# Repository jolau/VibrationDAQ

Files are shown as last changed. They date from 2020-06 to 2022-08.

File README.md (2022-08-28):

# VibrationDAQ
Data Acquisition (DAQ) of the [Analog Devices ADcmXL3021](https://www.analog.com/en/products/adcmxl3021.html#product-overview) vibration sensor. The VibrationDAQ was developed as part of an internship at [Wingtra](https://wingtra.com/) by [Jonas Lauener](https://www.jolau.ch/).  

**For any technical questions, please open an issue: https://github.com/jolau/VibrationDAQ/issues/new/choose**

Copyright (c) 2020, Jonas Lauener & Wingtra AG\


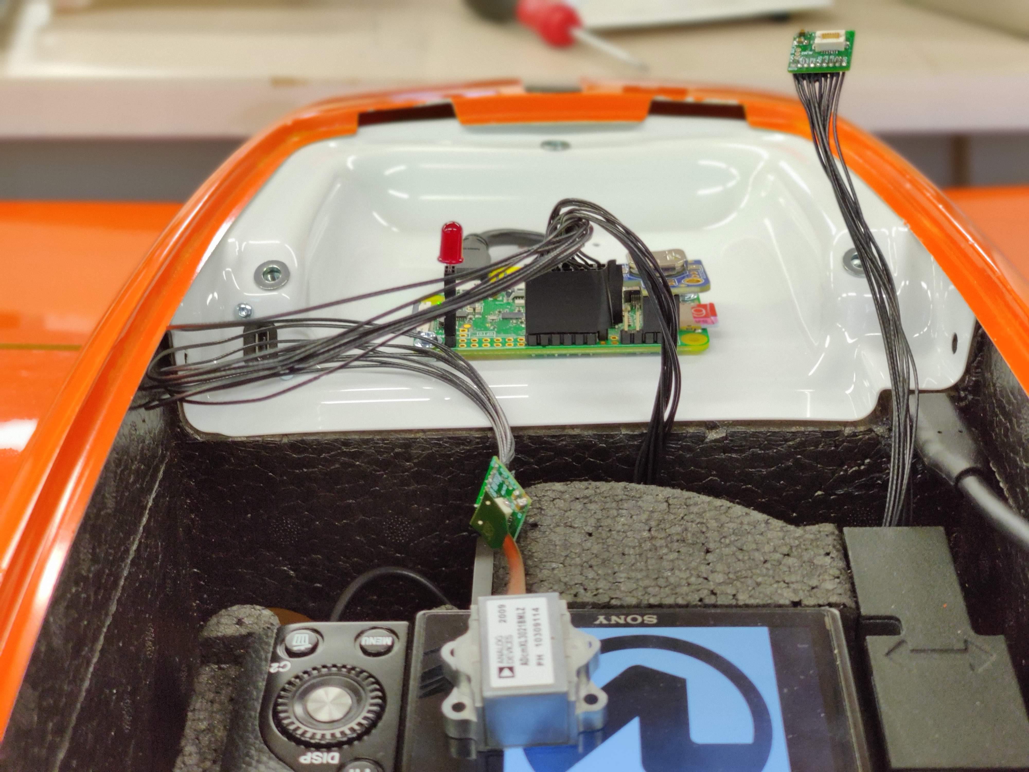
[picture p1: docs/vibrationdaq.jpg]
VibrationDAQ


## Hardware
- Raspberry Pi 
- [Analog Devices ADcmXL3021](https://www.analog.com/en/products/adcmxl3021.html#product-overview) vibration sensor capabilities
    - [Corrected data sheet](docs/ADcmXL3021_corrected.pdf)
    - Sensor orientation:\
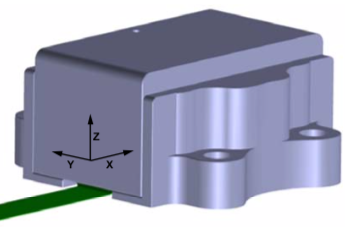
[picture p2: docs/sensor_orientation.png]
Sensor Orientation
    
    - Mass: 13 g
    - Frequencies up to 110 kHz
    - ±50 g measurement range
    - MFFT mode: Spectral analysis through internal FFT\
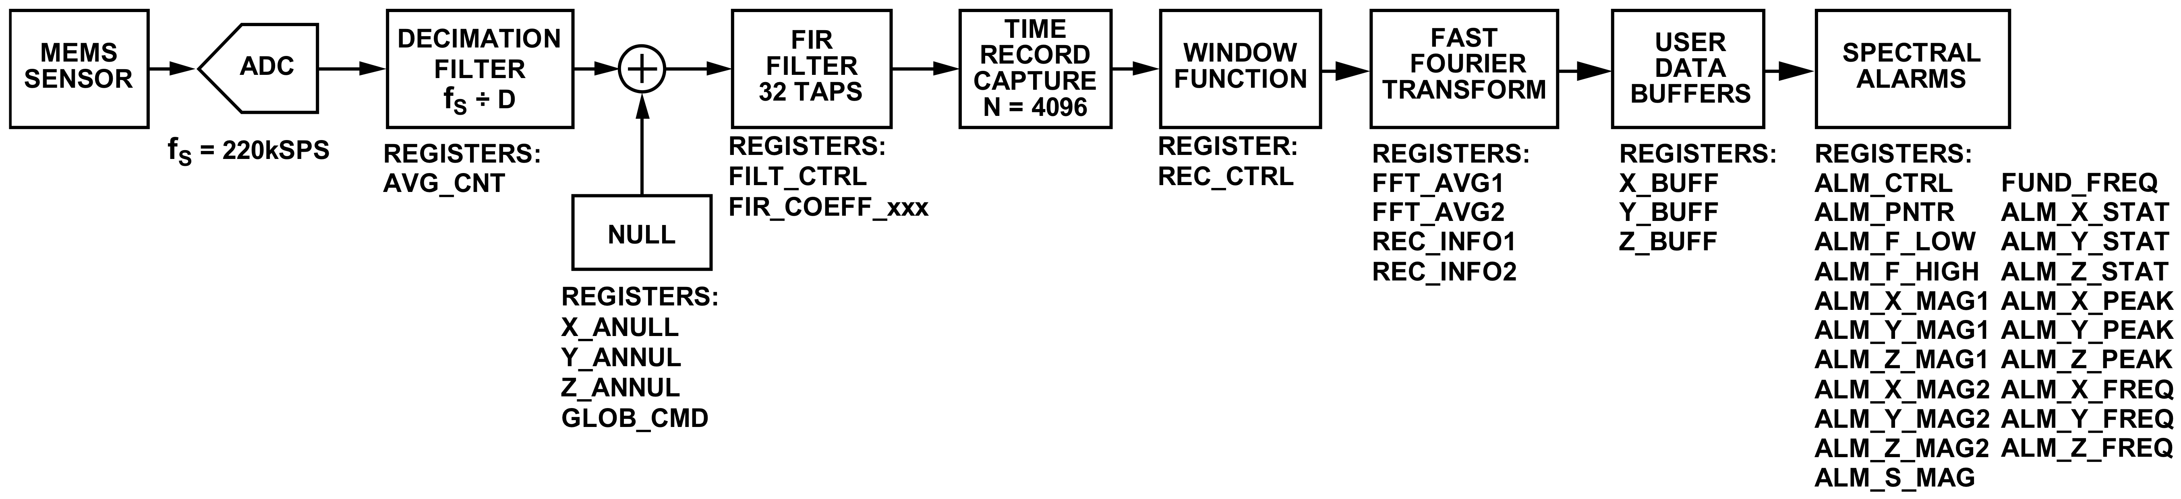
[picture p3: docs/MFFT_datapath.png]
MFFT datapath
    
        - 2048 bins per axis with user configurable bin sizes from 0.42 Hz to 53.7 Hz
        - Windowing options: rectangular, Hanning, flat top
    - MTC mode: Time domain capture\
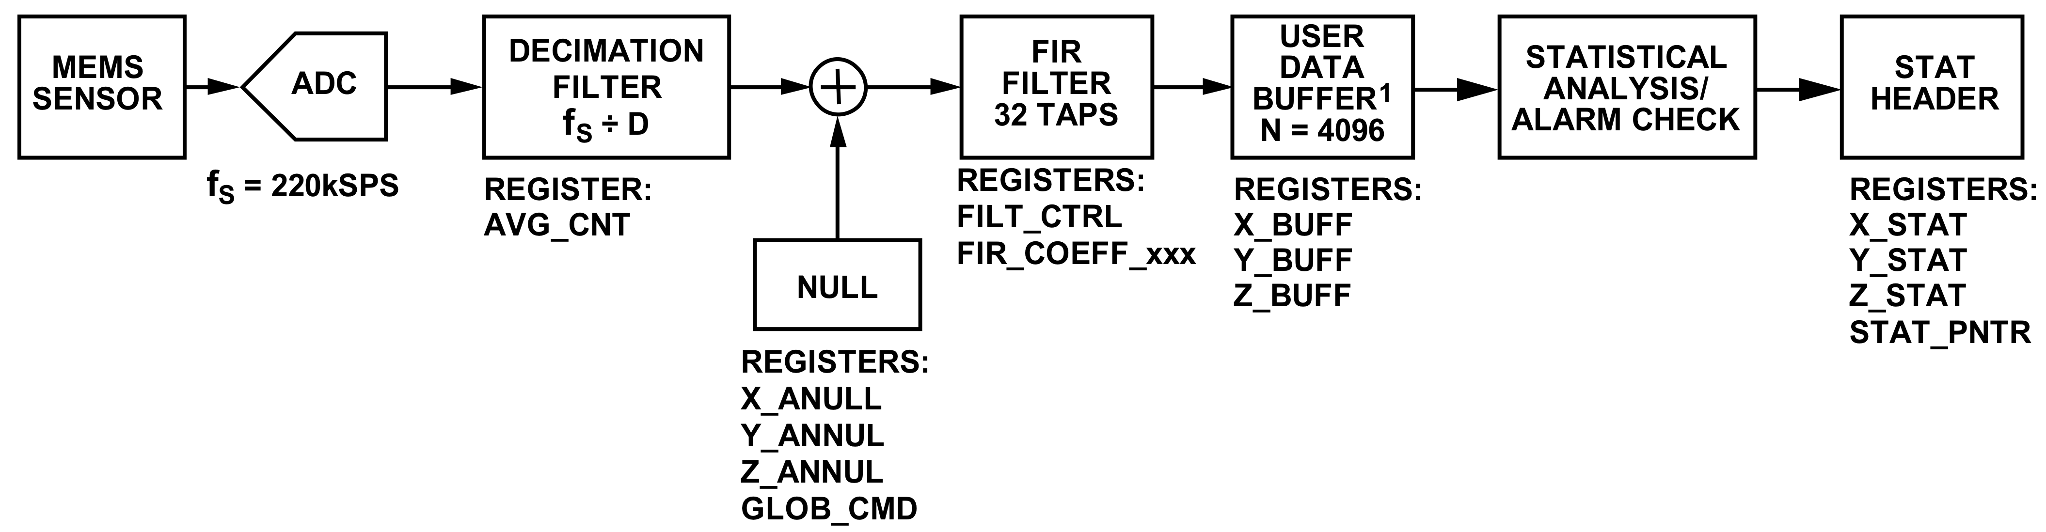
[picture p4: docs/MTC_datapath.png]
MTC datapath
    
        - 4096 samples per axis
- [Features a status LED](#status-led)

### Pinout Raspberry Pi
pinout rpi

| | pin | pin | |
|---|-----|-----|---|
| RST 1 | 13  | | |
| BSY 1 | 15  | 16  | RST 2 |
| 3V3 | 17  | 18  | BSY 2 |
| MOSI  | 19  | 20  | EMPTY |
| MISO  | 21  | 22  | SYNC  |
| SCLK  | 23  | 24  | CE 1  |
| GND | 25  | 26  | CE 2  |

The vibration sensor only works on the main SPI pins (SPI0) of the Raspberry Pi - the other SPI ports don't support SPI mode 3.

### Custom adapter board
The pins of the ADcmXL3021 vibration sensor can be accessed by using a custom adapter board. The PCB was created by using the software KiCad: [KiCad project files](ADcmXL3021_adapter/ADcmXL3021_adapter.pro)\
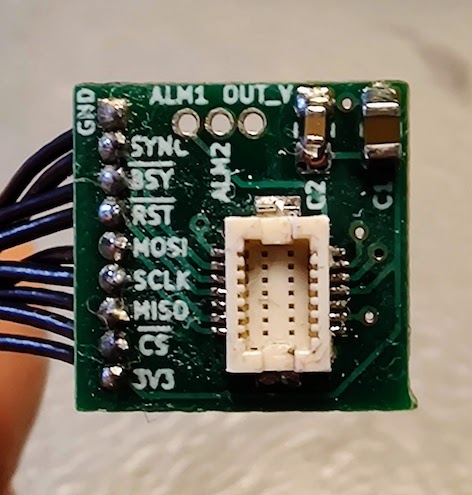
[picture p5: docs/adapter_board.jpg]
adapter board


## Installation
_In case you want to setup your own VibrationDAQ on a Raspberry Pi:_
1. Install yaml-cpp (as described below)
2. Clone this repo.
3. `cd VibrationDAQ`
4. `mkdir build & cd build`
5. `cmake ..`
6. `sudo make install`

Make sure that you have [enabled SPI](https://www.raspberrypi-spy.co.uk/2014/08/enabling-the-spi-interface-on-the-raspberry-pi/).

You can use it now with `vibration_daq_app [full path to config.yaml]`.

#### Installation of yaml-cpp
1. `wget https://github.com/jbeder/yaml-cpp/archive/yaml-cpp-0.6.3.tar.gz`
2. `tar -xvf yaml-cpp-0.6.3.tar.gz`
3. `cd yaml-cpp-yaml-cpp-0.6.3/`
4. `mkdir build`
5. `cd build`
6. `cmake .. -DYAML_BUILD_SHARED_LIBS=ON`
7. `sudo make install`

### Enable/Disable auto-start
1. Edit config.yaml path in vibration_daq.service file to own needs 
2. `sudo systemctl enable [full path to vibration_daq.service file]`    
    This automatically links the service and enables it. Replace `enable` with `disable` to disable service.

## Dependencies
Many thanks to the authors of the following libraries:
- [yaml-cpp](https://github.com/jbeder/yaml-cpp)
- [loguru](https://github.com/emilk/loguru)
- [c-periphery](https://github.com/vsergeev/c-periphery)
- [date](https://github.com/HowardHinnant/date)

## Usage
### Workflow
1. Connect to the Raspberry Pi and adapt the `~/Documents/config.yaml` to your requirements. Make sure that auto-start is enabled. If it's the first time you use it, test it by running it manually: `vibration_daq_app [full path to config.yaml]`
2. Mount the vibration sensor with the double sided tape [3M™ Adhesive Transfer Tape 950](https://www.digikey.ch/product-detail/en/3m-tc/3-4-5-950/3M9743-ND/2649288). This shouldn't distort the vibration too much.
3. Do your measurement.
4. Download the collected data over SFTP. I recommend to also download the used config file.
6. Open a vibration CSV file in Google Sheets. 
    - For FFT measurement: 
        - Hide the first two data points as these have usually very high magnitude and don't give meaningful information
        - Plot the data using a column chart.  

### Status led
If the status led is enabled in config, it will glow when running:
- Constant glow: data acquisition is running normally
- Blink: measurement completed, saving data to a new csv file

## Config file
Short primer on the syntax of yaml: https://learnxinyminutes.com/docs/yaml/

### Decimation Filter
Setting the right `decimation_factor` is crucial for getting meaningful data. Choose it according to the maximum vibration frequency you're expecting.
Of course, the decimation factor also affects the predefined FIR filters i.e. with a FACTOR_64, the LOW_PASS_10kHz is actually a 156 Hz low pass filter.  
 
| **decimation_factor** | **Effective Sample Rate, fS (SPS)** | **Effective FFT Bin Size, f_MIN (Hz)** | **Effective Maximum FFT Frequency, f_MAX (Hz)** |
|---|---|---|---|
| FACTOR_1 | 220000 | 53.71094 | 110000 |
| FACTOR_2 | 110000 | 26.85547 | 55000 |
| FACTOR_4 | 55000 | 13.42773 | 27500 |
| FACTOR_8 | 27500 | 6.713867 | 13750 |
| FACTOR_16 | 13750 | 3.356934 | 6875 |
| FACTOR_32 | 6875 | 1.678467 | 3437.5 |
| FACTOR_64 | 3437.5 | 0.839233 | 1718.75 |
| FACTOR_128 | 1718.75 | 0.419617 | 859.375 |

### Spectral average count
The `spectral_avg_count` determines the number of FFT records that the ADcmXL3021 averages when generating the final FFT result. Up to 255 records. Good for getting FFT measurements over longer time periods.

### Calculate measurement duration
#### FFT
4096 samples / (220'000 sample rate / `decimation_factor`) * `spectral_avg_count` = record time [s]

##### Example with FACTOR_64 and 255 spectral averages:
4096 samples / (220000 sample rate / 64) * 255 = 303.84 seconds = 5.06 minutes

#### MTC
4096 samples / (220'000 sample rate / `decimation_factor`) = record time [s]

### Example config with explanation
```yaml
storage_directory: "/home/pi/Documents/"
recordings_count: 2 #number of recurring measurements, infinite if == 0 
external_trigger: false # false: triggering over SPI; 
                        # true: triggering over dedicated pin, useful for triggering multiple sensor at exact same time (connect them to same pin)
external_trigger_pin: 4 # only read if external_trigger == true
status_led: true # enable/disable status led, blinks everytime a vibration file is written
status_led_pin: 21  # only read if status_led == true
sensors:
  - name: sensor1 #will be used for logging and filenames
    busy_pin: 22 #BCM pin number
    reset_pin: 27 #BCM pin number
    spi_path: "/dev/spidev0.0"
    recording_mode: MFFT # MTC and MFFT supported
    MFFT_config: &mfftConfig #only read if recording_mode == MFFT
      decimation_factor: FACTOR_2 #supported: [FACTOR_1 = 0, FACTOR_2 = 1, FACTOR_4 = 2, FACTOR_8 = 3, FACTOR_16 = 4, FACTOR_32 = 5, FACTOR_64 = 6, FACTOR_128 = 7]
      fir_filter: CUSTOM #supported: [NO_FILTER, LOW_PASS_1kHz, LOW_PASS_5kHz, LOW_PASS_10kHz, HIGH_PASS_1kHz, HIGH_PASS_5kHz, HIGH_PASS_10kHz, CUSTOM]
      custom_filter_taps: [6, 21, 53, 107, 193, 316, 480, 686, 930, 1203, 1490, 1774, 2034, 2251, 2407, 2489, 2489, 2407, 2251, 2034, 1774, 1490, 1203, 930, 686, 480, 316, 193, 107, 53, 21, 6]
      spectral_avg_count: 2 # value between 1-255
      window_setting: HANNING #supported: [RECTANGULAR, HANNING, FLAT_TOP]
    MTC_config: #only read if recording_mode == MTC
        decimation_factor: FACTOR_2
        fir_filter: CUSTOM
        custom_filter_taps: [6, 21, 53, 107, 193, 316, 480, 686, 930, 1203, 1490, 1774, 2034, 2251, 2407, 2489, 2489, 2407, 2251, 2034, 1774, 1490, 1203, 930, 686, 480, 316, 193, 107, 53, 21, 6]
  - name: sensor2
    busy_pin: 24
    reset_pin: 23
    spi_path: "/dev/spidev0.1"
    recording_mode: MFFT
    MFFT_config: *mfftConfig #copy config from sensor1 above
```

## Example data
The following data was collected on a self-made vibration bench. The bench consists of an unbalanced mass attached to an electrical motor. 
- [MFFT raw data example](docs/vibration_data_MFFT_2020-06-17T16_08_57.423_sensor1.csv)
    - Plot of MFFT data:\
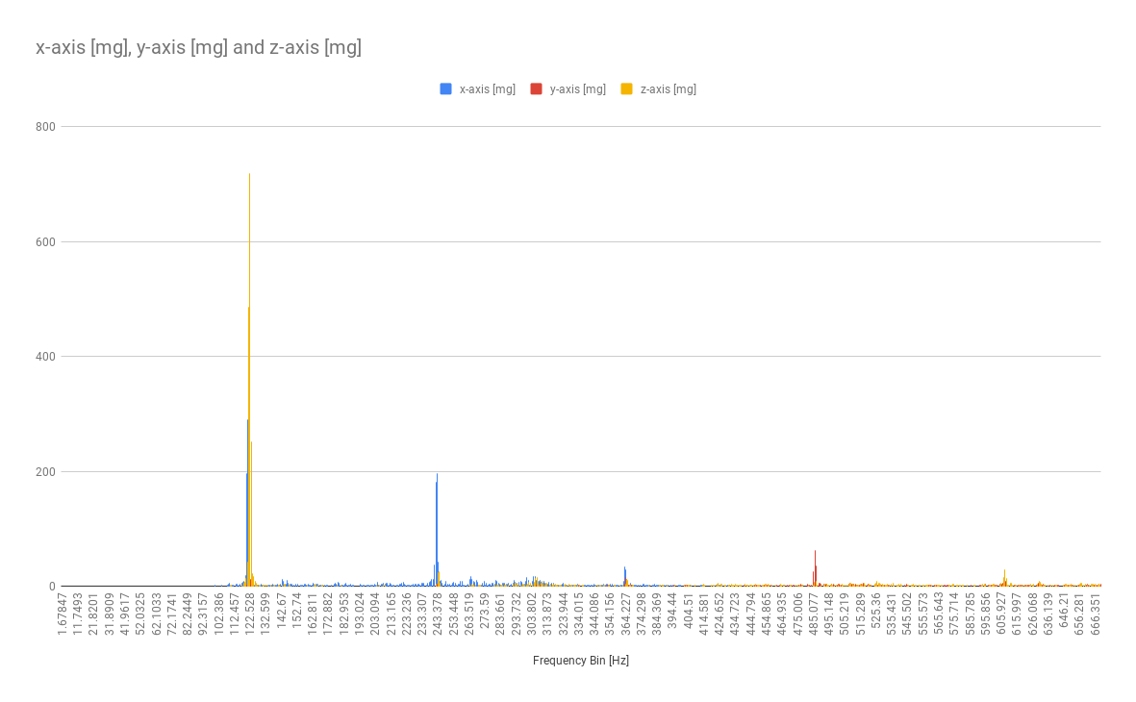
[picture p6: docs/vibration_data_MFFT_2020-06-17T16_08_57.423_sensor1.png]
MFFT plot
       
- [MTC raw data example](docs/vibration_data_MTC_2020-06-25T07_34_45.609_sensor1.csv)

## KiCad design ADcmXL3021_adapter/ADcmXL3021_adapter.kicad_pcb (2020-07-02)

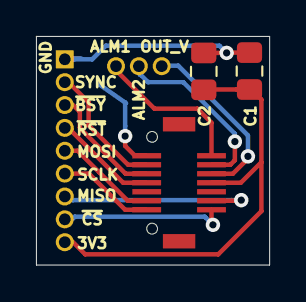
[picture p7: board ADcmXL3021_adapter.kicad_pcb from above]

Board: 2 copper layers, 13.0 x 12.7 mm, 5 parts (0 on the bottom side), 12 nets.

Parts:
C1: 10UF 25V; C_0805_2012Metric_Pad1.15x1.40mm_HandSolder
C2: 1UF 25V; C_0805_2012Metric_Pad1.15x1.40mm_HandSolder
J1: DF12(3.0)-14DP-0.5V(86); Hirose_DF12(3.0)-14DP-0.5V(86)
J2: Pin Header; PinHeader_1x09_P1.27mm_Vertical
J3: Aux Pin Header; PinHeader_1x03_P1.27mm_Vertical

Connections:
+3V3: C1.1, C2.1, J1.8, J2.9
/ALM1: J1.2, J3.1
/ALM2: J1.4, J3.2
/MISO: J1.12, J2.7
/MOSI: J1.11, J2.5
/OUT_VDDM: J1.6, J3.3
/SCLK: J1.13, J2.6
/SYNC_RTS: J1.3, J2.2
/~BUSY~: J1.5, J2.3
/~CS~: J1.14, J2.8
/~RST~: J1.7, J2.4
GND: C1.2, C2.2, J1.1, J2.1

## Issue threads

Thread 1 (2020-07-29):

RTC mode?

kumar10725, 2020-07-29:
Amazing work with your library for adcmxl3021.
Out of curiosity, have you ever got RTC mode to work with raspberry pi?

jolau, 2020-07-29:
No, I didn't try to use RTC mode.

Closed 2020-07-29.

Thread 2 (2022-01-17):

VibrationDAQ Velocity

biro52, 2022-01-17:
Good morning to get the speed by enabling
bit 5 on REC_CTRL, a factor is needed
correction?

jolau, 2022-01-17:
Recording velocity is currently not supported. You'll have to add this functionality yourself.

Closed 2022-01-17.

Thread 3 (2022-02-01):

VibrationDAQ - Velocity

biro52, 2022-02-01:
[Jolau.txt](https://github.com/jolau/VibrationDAQ/files/7980072/Jolau.txt)

jolau, 2022-08-28:
If it's still an issue, please create a new issue with the problem description inline instead of a txt-file.

Closed 2022-08-28.

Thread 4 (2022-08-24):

Data doesn‘t show up

6ent, 2022-08-24:
Hello,

I have installed everything as described in Readme. After enabling the auto start, the data is not being captured in my wished destination path. I adjusted service file and config.yaml.

thank you

6ent

jolau, 2022-08-26:
Hi, does it work when you start it manually?

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

6ent, 2022-08-26:
I am running the command systemctl enable [path to service file]. I am not using an external trigger.

After I‘ve run the service. which steps are required ?

Am 26.08.2022 um 11:05 schrieb JoLau ***@***.***>:

Hi, does it work when you start it manually?

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

—
Reply to this email directly, view it on GitHub<https://github.com/jolau/VibrationDAQ/issues/4#issuecomment-1228249329>, or unsubscribe<https://github.com/notifications/unsubscribe-auth/AVA7RSM673UXAGB2RGWMCZLV3CCEDANCNFSM57RAPIPA>.
You are receiving this because you authored the thread.Message ID: ***@***.***>

jolau, 2022-08-28:
Have you tested it by manually running it with `vibration_daq_app [full path to config.yaml]` first?

jolau, 2022-10-11:
But does the app work if you just start in manually?

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

Closed 2025-06-30.

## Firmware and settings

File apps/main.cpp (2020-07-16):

/* Copyright (c) 2020, Jonas Lauener & Wingtra AG
 * This Source Code Form is subject to the terms of the Mozilla Public
 * License, v. 2.0. If a copy of the MPL was not distributed with this
 * file, You can obtain one at https://mozilla.org/MPL/2.0/. */

#include <iostream>
#include <vibration_daq/VibrationSensorModule.hpp>
#include <vibration_daq/utils/HexUtils.hpp>
#include <filesystem>
#include <vibration_daq/ConfigModule.hpp>
#include "loguru/loguru.hpp"
#include <fstream>
#include <date/date.h>
#include <chrono>
#include <date/tz.h>
#include <vibration_daq/StorageModule.hpp>
#include "chrono"
#include "thread"
#include "yaml-cpp/yaml.h"
#include "date/date.h"

using namespace vibration_daq;
using namespace std::this_thread; // sleep_for, sleep_until
using namespace std::chrono; // nanoseconds, system_clock, seconds

static const int SPI_SPEED = 14000000;
gpio_t *gpioTrigger;
gpio_t *gpioStatusLed;

std::vector<VibrationSensorModule> vibrationSensorModules;
ConfigModule configModule;
StorageModule storageModule;

bool setupVibrationSensorModules(const bool &externalTriggerActivated);

system_clock::time_point triggerVibrationSensors(const bool &externalTrigger);

int main(int argc, char *argv[]) {
    loguru::g_preamble_uptime = false;
    loguru::g_preamble_thread = false;
    loguru::init(argc, argv);

    std::string configFilePath = "";
    if (argc > 1) {
        configFilePath = argv[1];
    } else {
        LOG_S(ERROR) << "No config file as program argument specified!";
        return EXIT_FAILURE;
    }

    LOG_S(INFO) << "Loading from config file path: " << configFilePath;
    if (!configModule.setup(configFilePath)) {
        LOG_S(ERROR) << "Could not setup ConfigModule.";
        return EXIT_FAILURE;
    }

    bool externalTriggerActivated = false;
    int externalTriggerPin = -1;
    if (!configModule.readExternalTriggerConfig(externalTriggerActivated, externalTriggerPin)) {
        LOG_S(ERROR) << "Could not retrieve externalTrigger config.";
        return EXIT_FAILURE;
    }
    if (externalTriggerActivated) {
        gpioTrigger = gpio_new();
        if (gpio_open(gpioTrigger, "/dev/gpiochip0", externalTriggerPin, GPIO_DIR_OUT_LOW) < 0) {
            LOG_F(ERROR, "gpio_open(): %s", gpio_errmsg(gpioTrigger));
            return EXIT_FAILURE;
        }
    }

    bool statusLedActivated = false;
    int statusLedPin = -1;
    if (!configModule.readStatusLedConfig(statusLedActivated, statusLedPin)) {
        LOG_S(ERROR) << "Could not retrieve externalTrigger config.";
        return EXIT_FAILURE;
    }
    if (statusLedActivated) {
        gpioStatusLed = gpio_new();
        if (gpio_open(gpioStatusLed, "/dev/gpiochip0", statusLedPin, GPIO_DIR_OUT_LOW) < 0) {
            LOG_F(ERROR, "gpio_open(): %s", gpio_errmsg(gpioStatusLed));
            return EXIT_FAILURE;
        }
    }


    if (!setupVibrationSensorModules(externalTriggerActivated)) {
        return EXIT_FAILURE;
    }

    std::string storageDirectoryPath;
    if (!configModule.readStorageDirectoryPath(storageDirectoryPath)) {
        LOG_S(ERROR) << "Could not retrieve storage_directory from config.";
        return EXIT_FAILURE;
    }
    if (!storageModule.setup({storageDirectoryPath})) {
        LOG_S(ERROR) << "Could not setup StorageModule.";
        return EXIT_FAILURE;
    }

    int recordingsCount;
    if (!configModule.readRecordingsCount(recordingsCount)) {
        recordingsCount = 1;
    }

    if (statusLedActivated && gpio_write(gpioStatusLed, true) < 0) {
        fprintf(stderr, "gpio_write(): %s", gpio_errmsg(gpioStatusLed));
        exit(1);
    }

    // run indefinitely if recordingsCount == 0
    for (int i = 0; i < recordingsCount || recordingsCount == 0; ++i) {
        system_clock::time_point triggerTime = triggerVibrationSensors(externalTriggerActivated);

        for (const auto &vibrationSensorModule : vibrationSensorModules) {
            auto vibrationData = vibrationSensorModule.retrieveVibrationData();

            if (statusLedActivated && gpio_write(gpioStatusLed, false) < 0) {
                fprintf(stderr, "gpio_write(): %s", gpio_errmsg(gpioStatusLed));
                exit(1);
            }

            bool storedVibrationData = storageModule.storeVibrationData(vibrationData,
                                                                        vibrationSensorModule.getSensorName(),
                                                                        triggerTime);

            if (statusLedActivated && gpio_write(gpioStatusLed, true) < 0) {
                fprintf(stderr, "gpio_write(): %s", gpio_errmsg(gpioStatusLed));
                exit(1);
            }

            LOG_IF_F(ERROR, !storedVibrationData, "Could not store vibration data.");
        }


    }

    for (auto &vibrationSensorModule : vibrationSensorModules) {
        vibrationSensorModule.close();
    }

    if (externalTriggerActivated) {
        gpio_close(gpioTrigger);
        gpio_free(gpioTrigger);
    }

    if (statusLedActivated) {
        if (gpio_write(gpioStatusLed, false) < 0) {
            fprintf(stderr, "gpio_write(): %s", gpio_errmsg(gpioStatusLed));
            exit(1);
        }

        gpio_close(gpioStatusLed);
        gpio_free(gpioStatusLed);
    }

    return EXIT_SUCCESS;
}

system_clock::time_point triggerVibrationSensors(const bool &externalTrigger) {
    system_clock::time_point triggerTime;
    if (externalTrigger) {
        if (gpio_write(gpioTrigger, true) < 0) {
            fprintf(stderr, "gpio_write(): %s", gpio_errmsg(gpioTrigger));
            exit(1);
        }

        triggerTime = system_clock::now();
        LOG_S(INFO) << "Triggered over PIN.";
        sleep_for(5ms);

        if (gpio_write(gpioTrigger, false) < 0) {
            fprintf(stderr, "gpio_write(): %s", gpio_errmsg(gpioTrigger));
            exit(1);
        }
    } else {
        for (const auto &vibrationSensorModule : vibrationSensorModules) {
            // start recording
            LOG_S(INFO) << vibrationSensorModule.getSensorName() << " triggered over SPI.";
            vibrationSensorModule.triggerRecording();
        }
        triggerTime = system_clock::now();
    }

    return triggerTime;
}

bool setupVibrationSensorModules(const bool &externalTriggerActivated) {
    std::vector<VibrationSensorConfig> vibrationSensorConfigs;
    if (!configModule.readVibrationSensors(vibrationSensorConfigs)) {
        LOG_S(ERROR) << "Could not retrieve vibration sensors from config.";
        return false;
    }

    for (const auto &vibrationSensorConfig : vibrationSensorConfigs) {
        VibrationSensorModule vibrationSensorModule(vibrationSensorConfig.name);
        if (!vibrationSensorModule.setup(vibrationSensorConfig.resetPin, vibrationSensorConfig.busyPin,
                                         vibrationSensorConfig.spiPath,
                                         SPI_SPEED)) {
            LOG_S(ERROR) << "Could not setup vibration sensor: " << vibrationSensorConfig.name;
            return false;
        }

        if (externalTriggerActivated) {
            vibrationSensorModule.activateExternalTrigger();
        }

//        vibrationSensorModule.triggerAutonull();
//        vibrationSensorModule.restoreFactorySettings();

        switch (vibrationSensorConfig.recordingMode) {
            case RecordingMode::MFFT:
                vibrationSensorModule.activateMode(vibrationSensorConfig.mfftConfig);
                break;
            case RecordingMode::MTC:
                vibrationSensorModule.activateMode(vibrationSensorConfig.mtcConfig);
                break;
        }

        vibrationSensorModules.push_back(vibrationSensorModule);
        LOG_S(INFO) << vibrationSensorModule.getSensorName() << " setup done";
    }

    return true;
}

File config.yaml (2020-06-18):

storage_directory: "/home/pi/Documents/"
recordings_count: 2
external_trigger: true
external_trigger_pin: 25
status_led: true
status_led_pin: 21
sensors:
  - name: sensor1
    busy_pin: 22
    reset_pin: 27
    spi_path: "/dev/spidev0.0"
    recording_mode: MFFT
    MFFT_config: &mfftConfig
      decimation_factor: FACTOR_64
      fir_filter: LOW_PASS_10kHz
      custom_filter_taps: [6, 21, 53, 107, 193, 316, 480, 686, 930, 1203, 1490, 1774, 2034, 2251, 2407, 2489, 2489, 2407, 2251, 2034, 1774, 1490, 1203, 930, 686, 480, 316, 193, 107, 53, 21, 6]
      spectral_avg_count: 1
      window_setting: HANNING
    MTC_config: &mtcConfig
        decimation_factor: FACTOR_1
        fir_filter: NO_FILTER
        custom_filter_taps: [6, 21, 53, 107, 193, 316, 480, 686, 930, 1203, 1490, 1774, 2034, 2251, 2407, 2489, 2489, 2407, 2251, 2034, 1774, 1490, 1203, 930, 686, 480, 316, 193, 107, 53, 21, 6]
  - name: sensor2
    busy_pin: 24
    reset_pin: 23
    spi_path: "/dev/spidev0.1"
    recording_mode: MFFT
    MFFT_config: *mfftConfig
    MTC_config: *mtcConfig

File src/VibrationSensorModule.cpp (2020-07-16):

/* Copyright (c) 2020, Jonas Lauener & Wingtra AG
 * This Source Code Form is subject to the terms of the Mozilla Public
 * License, v. 2.0. If a copy of the MPL was not distributed with this
 * file, You can obtain one at https://mozilla.org/MPL/2.0/. */

#include <vibration_daq/VibrationSensorModule.hpp>
#include "vibration_daq/utils/HexUtils.hpp"
#include <cmath>
#include <functional>
#include "chrono"
#include "thread"
#include "loguru/loguru.hpp"

namespace vibration_daq {
    using namespace std::this_thread; // sleep_for, sleep_until
    using namespace std::chrono_literals;

    VibrationSensorModule::VibrationSensorModule(const std::string &name) : name(name) {}

    const std::string &VibrationSensorModule::getSensorName() const {
        return name;
    }

    WordBuffer VibrationSensorModule::transfer(WordBuffer sendBuf) const {
        WordBuffer recBuf = {};
        if (spi_transfer(spi, sendBuf.data(), recBuf.data(), 2) < 0) {
            LOG_F(ERROR, "spi_transfer(): %s\n", spi_errmsg(spi));
            exit(1);
        }

        // keep processor busy to increase time of SPI disable to ~40us
        for (int i = 0; i < 2000; ++i) {
            // fixes the bug of shifting MISO 1 byte
        }

        return recBuf;
    }

    WordBuffer VibrationSensorModule::transferBlocking(WordBuffer sendBuf) const {
        bool notBusy;

        do {
            if (gpio_read(gpioBusy, &notBusy) < 0) {
                LOG_F(ERROR, "gpio_read(): %s\n", gpio_errmsg(gpioBusy));
                exit(1);
            }

            if (notBusy) {
                return transfer(sendBuf);
            } else {
                DLOG_S(INFO) << name << " is busy.";
                sleep_for(10ms);
            }
        } while (!notBusy);

        return {};
    }

    uint16_t VibrationSensorModule::read(vibration_daq::SpiCommand cmd) const {
        if (!cmd.readFlag) {
            LOG_S(ERROR) << name << ": Cannot read SpiCommand (PageID: " << cmd.pageId << ", Address: " << cmd.address
                         << "). Read flag not set.";
            return 0;
        }

        // select page
        transferBlocking({0x80, cmd.pageId});

        transferBlocking({cmd.address, 0});
        WordBuffer resp = transferBlocking({0, 0});

        return convert(resp);
    }

    void VibrationSensorModule::write(SpiCommand cmd, uint16_t value) const {
        if (!cmd.writeFlag) {
            LOG_S(ERROR) << name << ": Cannot write SpiCommand (PageID: " << cmd.pageId << ", Address: " << cmd.address
                         << "). Write flag not set.";
            return;
        }

        // select page
        transferBlocking({0x80, cmd.pageId});

        transferBlocking({static_cast<unsigned char>(cmd.address | 0x80), static_cast<unsigned char>(value & 0xff)});
        transferBlocking({static_cast<unsigned char>((cmd.address + 1) | 0x80), static_cast<unsigned char>(value >> 8)});
    }


    bool
    VibrationSensorModule::setup(unsigned int resetPin, unsigned int busyPin, std::string spiPath, uint32_t speed) {
        gpioReset = gpio_new();
        gpioBusy = gpio_new();

        if (gpio_open(gpioReset, GPIO_PATH.data(), resetPin, GPIO_DIR_OUT_LOW) < 0) {
            LOG_F(ERROR, "gpio_open(): %s\n", gpio_errmsg(gpioReset));
            return false;
        }
        if (gpio_open(gpioBusy, GPIO_PATH.data(), busyPin, GPIO_DIR_IN) < 0) {
            LOG_F(ERROR, "gpio_open(): %s\n", gpio_errmsg(gpioBusy));
            return false;
        }

        spi = spi_new();
        if (spi_open_advanced(spi, spiPath.data(), 3, speed, spi_bit_order_t::MSB_FIRST, 8, 0) < 0) {
            LOG_F(ERROR, "spi_open(): %s\n", spi_errmsg(spi));
            return false;
        }

        sleep_for(200ms);

        if (gpio_write(gpioReset, true) < 0) {
            LOG_F(ERROR, "gpio_write(): %s\n", gpio_errmsg(gpioReset));
            return false;
        }

        // important for transient behaviour of busy pin on startup!
        sleep_for(500ms);

        // check if the right model (ADcmXL3021) is connected and if the connection works
        uint16_t prodId = read(spi_commands::PROD_ID);
        if (prodId != 0x0BCD) {
            LOG_F(ERROR, "Not getting the right prodId, getting: 0x%04X", prodId);
            return false;
        }

        return true;
    }

    void VibrationSensorModule::close() {
        gpio_close(gpioBusy);
        gpio_close(gpioReset);

        gpio_free(gpioBusy);
        gpio_free(gpioReset);

        spi_close(spi);
        spi_free(spi);
    }

    bool VibrationSensorModule::writeRecordingControl(const RecordingMode &recordingMode,
                                                      const WindowSetting &windowSetting) {
        // hard type sample rate option 0
        uint16_t recCtrl = 0x100;

        recCtrl |= (static_cast<uint8_t>(windowSetting) << 12);
        recCtrl |= static_cast<uint8_t>(recordingMode);

        write(spi_commands::REC_CTRL, recCtrl);

        recCtrl = read(spi_commands::REC_CTRL);
        currentRecordingMode = static_cast<RecordingMode>(recCtrl & 0x3);

        return currentRecordingMode == recordingMode;
    }

    VibrationData VibrationSensorModule::retrieveVibrationData() const {
        int samplesCount = 0;
        float recordStepSize = 0;
        int decimationFactor = readRecInfoDecimationFactor();

        std::function<float(int16_t)> convertVibrationValue;
        switch (currentRecordingMode) {
            case RecordingMode::MTC:
                samplesCount = 4096;
                recordStepSize = 1.f / (220000.f / static_cast<float>(decimationFactor));
                convertVibrationValue = {
                        [](int16_t valueRaw) {
                            return static_cast<float>(valueRaw) * 0.001907349;
                        }
                };
                break;
            case RecordingMode::MFFT:
            case RecordingMode::AFFT:
                const uint8_t numberOfFFTAvg = readRecInfoFFTAveragesCount();
                samplesCount = 2048;
                recordStepSize = 110000.f / static_cast<float>(decimationFactor) / static_cast<float>(samplesCount);
                convertVibrationValue = {
                        [numberOfFFTAvg](int16_t valueRaw) {
                            // handle special case according to https://ez.analog.com/mems/f/q-a/162759/adcmxl3021-fft-conversion/372600#372600
                            if(valueRaw == 0) {
                                return 0.0;
                            }
                            return std::pow(2, static_cast<float>(valueRaw) / 2048) / numberOfFFTAvg * 0.9535;
                        }
                };
                break;
        }

        write(spi_commands::BUF_PNTR, 0);
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

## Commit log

2020-04-21 moved VibrationDAQ to its own dir
    [ConfigModule.cpp, FIRFilter.hpp]
2020-04-21 fixed external triggering & added to config
    [ConfigModule.cpp, config.yaml, main.cpp]
2020-04-27 better logging with multiple sensors
2020-04-27 more compact pin config
2020-04-28 better filenames for multiple sensors
2020-04-30 added cap. for autonull/reset & fft conversion special case handling
    [VibrationSensorModule.cpp, main.cpp]
2020-05-05 switched to utc time for filenames
2020-05-05 pwm led
    not stable
2020-05-05 status led simple & added to config
2020-05-06 fixed hardcoded led pin
    [main.cpp]
2020-07-02 added adapter board to git
    [ADcmXL3021_adapter.kicad_pcb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]
2020-07-16 added licences and info for public
    [ADcmXL3021_memory_map.ods, vibration_data_MFFT_2020-06-17T16_08_57.423_sensor1.csv, vibration_data_MTC_2020-06-25T07_34_45.609_sensor1.csv]

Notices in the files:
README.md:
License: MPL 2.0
